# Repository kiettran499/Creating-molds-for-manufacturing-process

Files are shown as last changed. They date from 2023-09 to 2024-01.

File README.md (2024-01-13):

# Creating-molds-for-manufacturing-process

<p align="center">
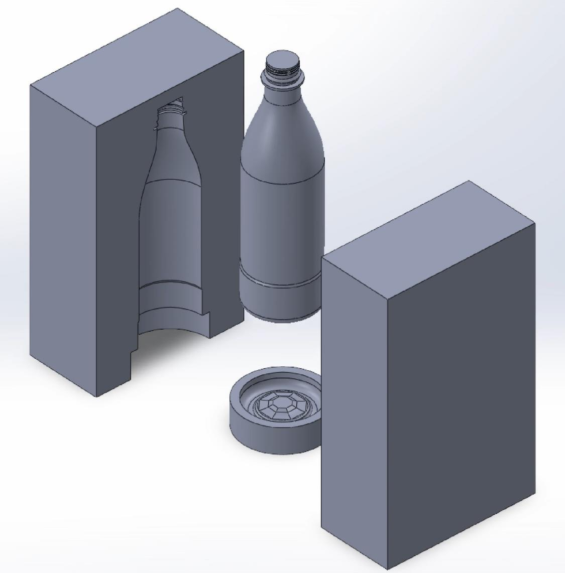
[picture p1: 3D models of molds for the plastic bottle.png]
  

## Description

- The project is to design molds for a plastic bottle manufacturing process called blow molding.
- The plastic bottle having a capacity of 500 ml, made of PET with a shrinkage coefficient of 0.4% when cooling.
- The molds are to be machined from a rectangular block of 150mm x 150mm x 250mm, made from 6061-T6 aluminum alloy.
- The bottle is constructed in Solidworks and the molds are created by Solidworks CAM.
- Because the bottle is non-conventional shape or designed with deep, narrow cavities that are difficult to reach, we use 3 axis mill operations.
- The toolings in Solidworks CAM have to be available on the market.
- By using Solidworks CAM, the G-code for machining all molds features will be developed while optimizing the tool path to minimize the total machining time for each part.

## Design & Result

-  Design of a plastic bottle.
<p align="center">
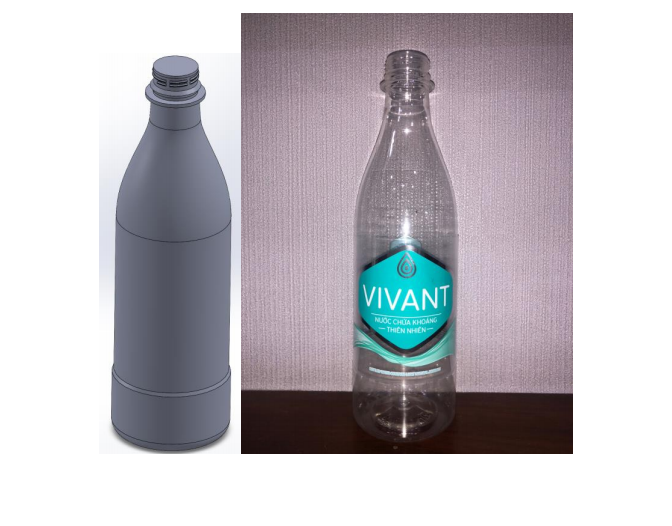
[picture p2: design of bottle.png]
  
  
- Final design of molds for the bottle.
<p align="center">
  

- Design in explode view (Animation GIF).
<p align="center">
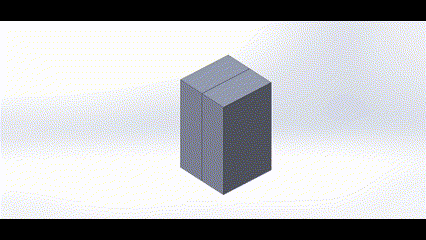
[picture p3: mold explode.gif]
  

- The estimated machining time for mold parts, resulting from our CNC programs:
  - Bottom Mold is 20.23 minutes = 20 minutes : 14 seconds.
  - Side 1 Mold is 105.91 minutes = 1 hour : 45 minutes :55 seconds.
  - Side 2 Mold is 99.53 minutes= 1 hour: 39 minutes : 32 seconds.

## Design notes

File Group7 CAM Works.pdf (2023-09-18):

## MANU2474 Computer Integrated Manufacturing – CAM Works

Team members:

Hoang Tong Minh Long | s3754662
Tran Anh Kiet | s3741189
Truong Minh Phu | s3752562
To Vu Phuc | s3758272
Lecturer: | Dr Son Dao

Submission date: 20 September 2022

- Reverse engineering design of a plastic bottle in Solidworks

In the first stage of our design, the 3D model of a plastic bottle having a capacity of 500 ml will be constructed in Solidworks.

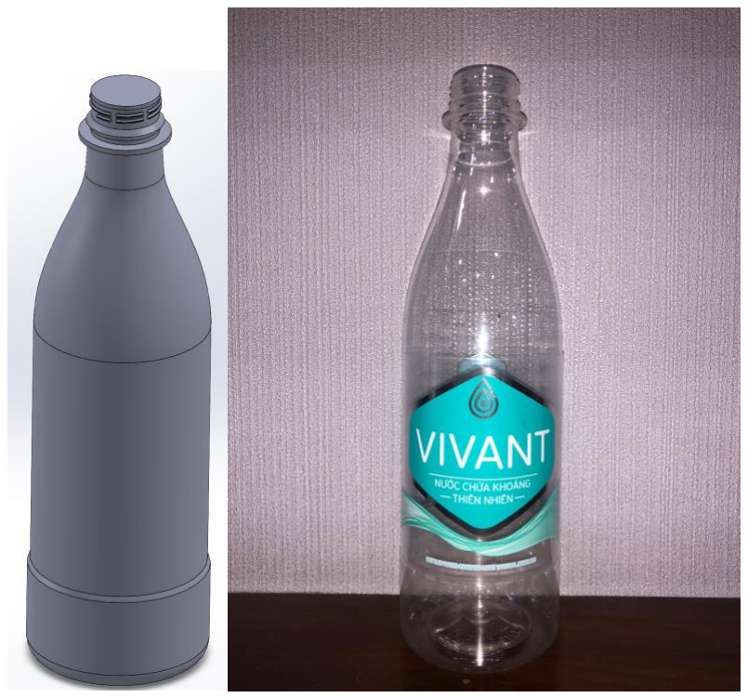
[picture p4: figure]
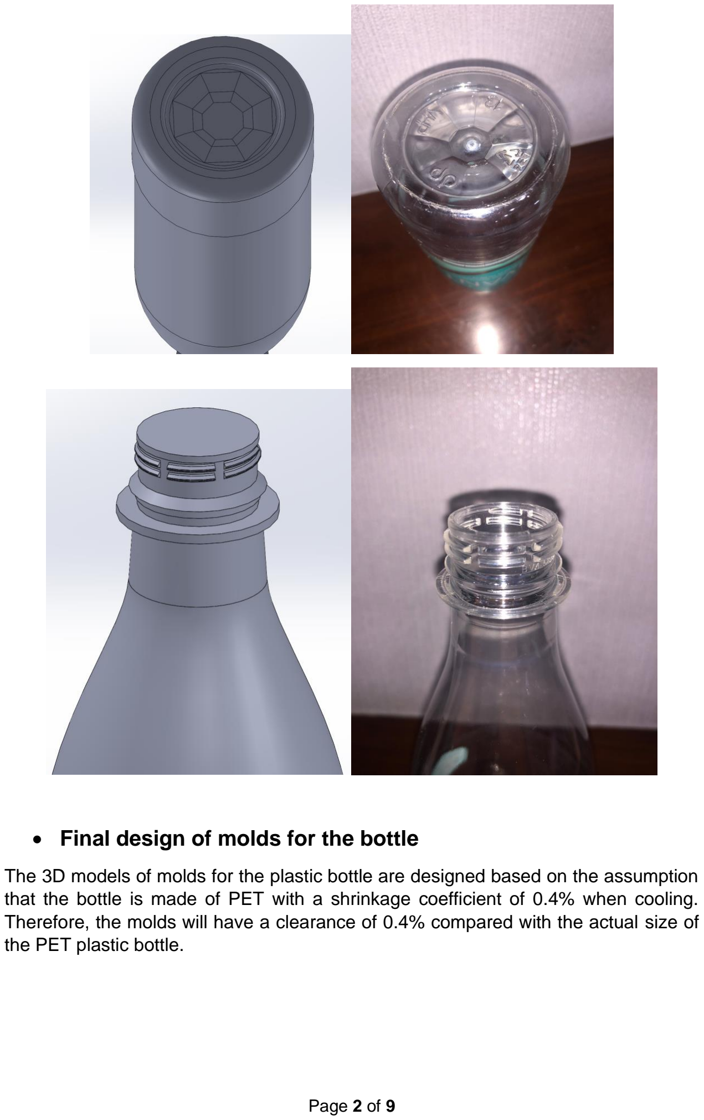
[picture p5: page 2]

- Final design of molds for the bottle

The 3D models of molds for the plastic bottle are designed based on the assumption that the bottle is made of PET with a shrinkage coefficient of 0.4% when cooling. Therefore, the molds will have a clearance of 0.4% compared with the actual size of the PET plastic bottle.

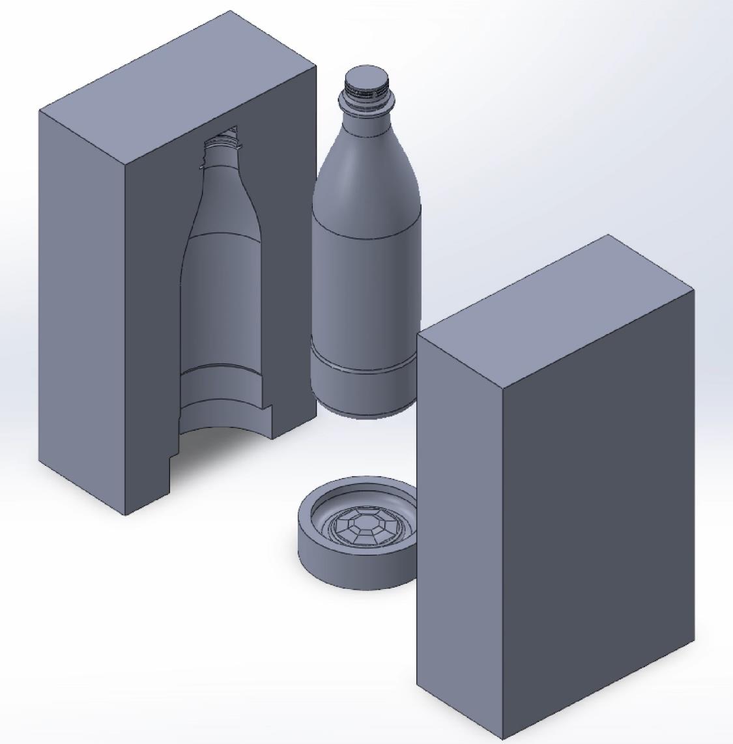
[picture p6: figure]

- Tools

Our molds would be made of Aluminum 6061-T6 and machined from a rectangular block of 150mm x 150mm x 250mm. The complex patterns at the bottom, as well as the bottle thread, requires specific tooling products available in the market. These tools are provided in the tables below.

Because the bottle is non-conventional shape or designed with deep, narrow cavities that are difficult to reach, we use 3 axis mill operations.

Bottom Mold’s Tools

No. | Tools | Products | Links | Description
1 | Flat end 16 mm 4 flutes | 16MM CRB 4FL 32 LOC | https://www.ebay.co.uk/itm/2715968696 40 (https://www.ebay.co.uk/itm/271596869640) | We use the large tool to make space for the smaller tool to cut easier and faster. Hence, it can save time

2 | Ball nose 6 mm 4 flutes | 6MM CRB 4FL BM 9 LOC | https://m.vi.aliexpress.com/item/32813382722.html?gatewayAdapt=glo2vnm (https://m.vi.aliexpress.com/item/32813382722.html?gatewayAdapt=glo2vnm) | Create details inside the mold and Make the surface of the mold become smoother.
3 | Ball nose 4 mm 4 flutes | 4MM CRB 4FL BM 14 LOC | https://www.ebay.com/itm/27542589246 4 (https://www.ebay.com/itm/275425892464) | Make the surface of the mold become smoother.
4 | Ball nose 1 mm 4 flutes | 1MM CRB 4FL BM 4 LOC | https://vn.misumi-ec.com/vona2/detail/223000580426/?list=PageCategory (https://vn.misumi-ec.com/vona2/detail/223000580426/?list=PageCategory) | Make the surface of the mold become smoother, especially the small details that larger tools hard to reach.
5 | Hog end tapered 6 degrees 5x1 mm | 5MM TAPERED HOGENDMILL 8 DEG TAPER | https://vn.misumi-ec.com/vona2/detail/223000569423/?list=PageCategory (https://vn.misumi-ec.com/vona2/detail/223000569423/?list=PageCategory) https://vn.misumi-ec.com/vona2/detail/223000580471/?list=PageCategory (https://vn.misumi-ec.com/vona2/detail/223000580471/?list=PageCategory) https://vn.misumi-ec.com/vona2/detail/223000569412/?list=PageCategory (https://vn.misumi-ec.com/vona2/detail/223000569412/?list=PageCategory) | Make the surface of the mold become smoother.

Side Mold 1 Tool

No. | Tools | Products | Link | Description
1 | Hog nose tapered 5x1 mm 6 degrees | 5MM TAPERED HOGENDMILL 6 DEG TAPER | https://conicalendmills.com/cutting-tools/special-application-end-mills/tapered-end-mill-hss/6-degree-tapered-end-mill-hss/ (https://conicalendmills.com/cutting-tools/special-application-end-mills/tapered-end-mill-hss/6-degree-tapered-end-mill-hss/) | Main tool used to create the major portion of the bottle-shaped pocket.

2 | Ball nose 3mm 4 flutes | 3MM CRB 4FL BM 6 LOC | https://www.ebay.com/itm/31 2900498357 (https://www.ebay.com/itm/312900498357) | Make the surface of the mold become smoother.
3 | Bore 1mm | ADJUSTABLE BORE 1MM -12.7MM | https://www.amazon.co.uk/Drill-Ground-Drills-AllTrade-Direct/dp/B00 S4Z8KPA (https://www.amazon.co.uk/Drill-Ground-Drills-AllTrade-Direct/dp/B00S4Z8KPA) | Good length & small diameter to machine the bottle thread
4 | 0.5mm jobber drill | 0.5mm JOBBER DRILL | https://www.ebay.com/itm/ME TRIC-Twist-Drills-HSS-10-Each-6-Sizes-0-5mm-1-0mm-Jobber-Drill-Bits-60-Pcs-/19081096381 8 (https://www.ebay.com/itm/METRIC-Twist-Drills-HSS-10-Each-6-Sizes-0-5mm-1-0mm-Jobber-Drill-Bits-60-Pcs-/190810963818) | It is used for small and inclined details.
5 | Ball nose 2mm | 2MM CRB 4FL BM 4 LOC2MM CRB 4FL BM 4 LOC | https://www.ebay.com.au/itm/26347032000 9 (https://www.ebay.com.au/itm/263470320009) | It is used for small details to slightly decrease the machining time.

6

Ball nose
0.5mm

0.5MM CRB
2FL BM 3
LOC

ttps://www.eba
y.com/itm/264
303791215?v
ar=563888136
020&norover=
1&mkevt=1&m
krid=21581-
161791-
616585-
7&mkcid=2&it
emid=563888
136020_2643
03791215&tar
getid=170687
2446233&devi
ce=m&mktype
=pla&googlelo
c=1028581&p
oi=&campaigni
d=181864018
95&mkgroupid
=1384619828 (https://www.ebay.com/itm/264303791215?var=563888136020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)

Very high
performance for
tiny features, in
exchange of
longer
machining time.

97&rlsatarget=
pla-17068724462
33&abcId=&m
erchantid=119
648210&gbrai
d=0AAAAAD_
QDh9dcDiRwc
FNj7x5MLDOs
sKqZ&gclid=Cj
wKCAjwyaWZ
BhBGEiwACsl
Qo7b_ixj8kYx
gB8lB4lN2RF
HeH6dWc-LUm8gmoWK
aY_dvOgMC9l
fPMhoCrbIQA
vD_BwE (https://www.ebay.com/itm/264303791215?var=563888136020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)
7 | Ball nose 1mm | 1MM CRB 4FL BM 4 LOC | https://www.ebay.com.au/itm/26347032000 9 (https://www.ebay.com.au/itm/263470320009) | It is used for tiny features and more suitable and cleaner than other tools.
8 | Flat end 4mm | 4MM CRB 4FL 8 LOC | https://www.amazon.com/C utting-4Flutes-Tungsten-Endmills-4mmDia%C3 %974mmShan k%C3%9775 mmOAL/dp/B0 1C5BIYL8 (https://www.amazon.com/Cutting-4Flutes-Tungsten-Endmills-4mmDia%C3%974mmShank%C3%9775mmOAL/dp/B01C5BIYL8) | It is used for surface smoothening at corners

Side Mold 2 Tools

No. | Tools | Products | Link | Description
1 | Ball nose 3mm 4 flutes | 3MM CRB 4FL BM 6 LOC | https://www.ebay.com/itm/31 2900498357 (https://www.ebay.com/itm/312900498357) | It is used for medium features with smoother surface finish.
2 | Bore 1mm | ADJUSTABLE | https://www.amazon.co.uk/Drill-Ground- (https://www.amazon.co.uk/Drill-Ground-Drills-AllTrade-Direct/dp/B00S4Z8KPA) | Good length & small diameter

| | BORE 1MM -12.7MM | Drills-AllTrade-Direct/dp/B00 S4Z8KPA (https://www.amazon.co.uk/Drill-Ground-Drills-AllTrade-Direct/dp/B00S4Z8KPA) | to machine the bottle thread.
3 | 0.5mm jobber drill | 0.5mm JOBBER DRILL | https://www.ebay.com/itm/ME TRIC-Twist-Drills-HSS-10-Each-6-Sizes-0-5mm-1-0mm-Jobber-Drill-Bits-60-Pcs-/19081096381 8 (https://www.ebay.com/itm/METRIC-Twist-Drills-HSS-10-Each-6-Sizes-0-5mm-1-0mm-Jobber-Drill-Bits-60-Pcs-/190810963818) | It is used for obstructed locations with small, inclined features.
4 | Hog nose tapered 5x1 mm 6 degrees | 5MM TAPERED HOGENDMILL 6 DEG TAPER | https://conicalendmills.com/cutting-tools/special-application-end-mills/tapered-end-mill-hss/6-degree-tapered-end-mill-hss/ (https://conicalendmills.com/cutting-tools/special-application-end-mills/tapered-end-mill-hss/6-degree-tapered-end-mill-hss/) | Main tool used to create the major portion of the bottle-shaped pocket.
5 | Ball nose 2 mm | 2MM CRB 4FL BM 4 LOC | https://www.ebay.com.au/itm/26347032000 9 (https://www.ebay.com.au/itm/263470320009) | It is used for small details to slightly decrease the machining time.
6 | Ball nose 0.5x0.25 mm | 0.5MM CRB 2FL BM 3 LOC | https://www.ebay.com/itm/264303791215?itemid=563888136020_264303791215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 (https://www.ebay.com/itm/264303791215?var=563888136020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) | Very high performance for tiny features, in exchange of longer machining time.

=pla&googlelo
c=1028581&p
oi=&campaigni
d=181864018
95&mkgroupid
=1384619828
97&rlsatarget=
pla-17068724462
33&abcId=&m
erchantid=119
648210&gbrai
d=0AAAAAD_
QDh9dcDiRwc
FNj7x5MLDOs
sKqZ&gclid=Cj
wKCAjwyaWZ
BhBGEiwACsl
Qo7b_ixj8kYx
gB8lB4lN2RF
HeH6dWc-LUm8gmoWK
aY_dvOgMC9l
fPMhoCrbIQA
vD_BwE (https://www.ebay.com/itm/264303791215?var=563888136020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)
7 | Ball nose 1 mm 4 flutes | 1MM CRB 4FL BM 4 LOC | https://www.ebay.com.au/itm/26347032000 9 (https://www.ebay.com.au/itm/263470320009) | High performance for tiny features.
8 | Flat End 4 mm | 4MM CRB 4FL 8 LOC | https://www.amazon.com/C utting-4Flutes-Tungsten-Endmills-4mmDia%C3 %974mmShan k%C3%9775 mmOAL/dp/B0 1C5BIYL8 (https://www.amazon.com/Cutting-4Flutes-Tungsten-Endmills-4mmDia%C3%974mmShank%C3%9775mmOAL/dp/B01C5BIYL8) | It is used for surface smoothening at corners.
- Machining Time

In the last stage, the G-code for machining all molds features will be developed while optimizing the tool path to minimize the total machining time for each part. The estimated machining time for mold parts, resulting from our CNC programs, is provided in the tables below.

Bottom Mold

Tools | Time (min)
Area Clearance 1 | 0.22
Z level 1 | 3.08
Flat Area 1 | 0.07
Z level 2 | 4.90
Flat Area 2 | 2.82
Z level 3 | 1.82
Z level 4 | 1.43
Z level 5 | 5.89
Total | 20.23 minutes = 20 minutes : 14 seconds

Side 1 Mold

Tools | Time (min)
Z level 1 | 37.68
Z level 2 | 15.44
Z level 3 | 26.89
Z level 4 | 20.54
Z level 5 | 2.12
Z level 6 | 1.11
Z level 7 | 1.97
Flat area1 | 0.16
Total | 105.91 minutes = 1 hour : 45 minutes :55 seconds

Side 2 Mold

Tools | Time (min)
Z level 1 | 10.39
Z level 2 | 15.39
Z level 3 | 49.75
Z level 4 | 20.51
Z level 5 | 1.99
Z level 6 | 0.33
Z level 7 | 1.02
Flat area1 | 0.15
Total | 99.53 minutes= 1 hour: 39 minutes : 32 seconds

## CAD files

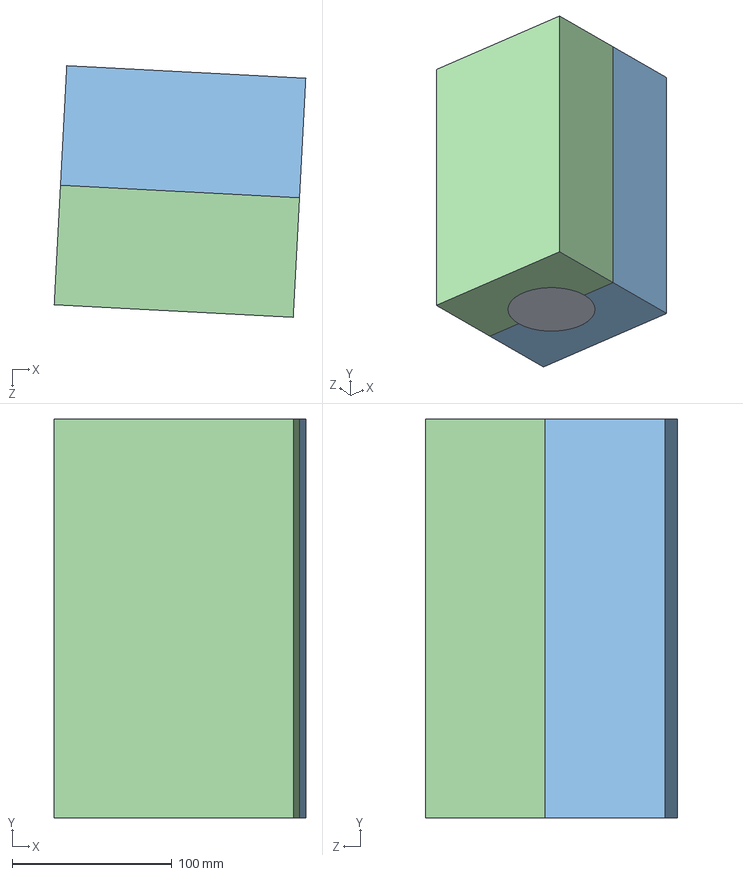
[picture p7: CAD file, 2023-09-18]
mold assembly.SLDASM
157.6 x 250.0 x 157.6 mm
Bottom mold
Vivant bottle plain
Mold1
Mold2
